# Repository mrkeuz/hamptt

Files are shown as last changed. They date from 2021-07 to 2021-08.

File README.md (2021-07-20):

Ham PTT
=======

Bluetooth PTT switch for ham radio transmitters like Baofeng UV-5R.  
Board helps to control transmitter from PC.

Motivation
----------

Testing of UART interface showed unstable connection. During transmit via UART an usb-ttl 
chip periodically crashes and stops working. Cause is some radio strong interference 
on USB cable. So Bluetooth serial protocol stack (SSP) chosen instead.

Schematic
---------

Host -> (Bluetooth) -> Esp-32 Arduino -> Relay -> Transmitter PTT button

* Hardware

    - Host PC with Bluetooth (tested Ubuntu 20.04)
    - Esp32 DevKit v1 (or similar esp32)
    - Relay shield
    - Baofeng UV-5R

Examples
--------

- Find BT devices `hcitool scan`
- Python

```python3
from hamptt import open_ptt

with open_ptt(bt_addr="A0:B1:C2:D3:E4:F5") as ptt:
    ptt.begin()
    # I.e. play message to transmitter or something else
    ptt.end()
```

Install
-------

* Host PC machine

    - Python 3.8
    - Bluetooth's libs (required for pybluez)

      ```shell
      sudo apt-get install bluez libbluetooth-dev
      ```

    - Pip
      ```shell
      python3 -m pip install "hamptt[bt]"
      ```

* Esp32

    - Upload sketch to your esp-32 via PlatformIO  
      NOTE! Check your board config in `platformio.ini` (see: https://platformio.org/)
      ```
      pio run -t upload
      ``` 

    - Connect pins Esp-32 to relay

        - VVC -> Relay +
        - GND -> Relay -
        - GPIO D25 -> Relay IN

    - Connect relay and audio, for Baofeng UV-5R it looks like:

      Baofeng UV-5R Pins  
      NOTE: You can rebuild your hands-free cable or buy another one

Development
===========

* Build and install
  ```shell
  pip3 uninstall hamptt
  rm -rf dist && poetry build && pip3 install ./dist/*.whl
  ```
  
* Publish
  - Prepare  
     ```shell
    poetry config repositories.testpypi https://test.pypi.org/legacy/
    poetry config pypi-token.testpypi <TOKEN>
    
    poetry config repositories.pypi https://upload.pypi.org/legacy/
    poetry config pypi-token.pypi <TOKEN>
    ```  
  
  - Publish
    ```shell
    poetry publish --build -r testpypi
    
    poetry publish --build -r pypi
    ````

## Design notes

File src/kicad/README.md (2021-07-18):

Esp32 PTT HAT
=============

PTT where using darlington array fot PTT instead relay. Compatible with `ESP32 WROOM DevKit v1` board

Screenshots
-----------  
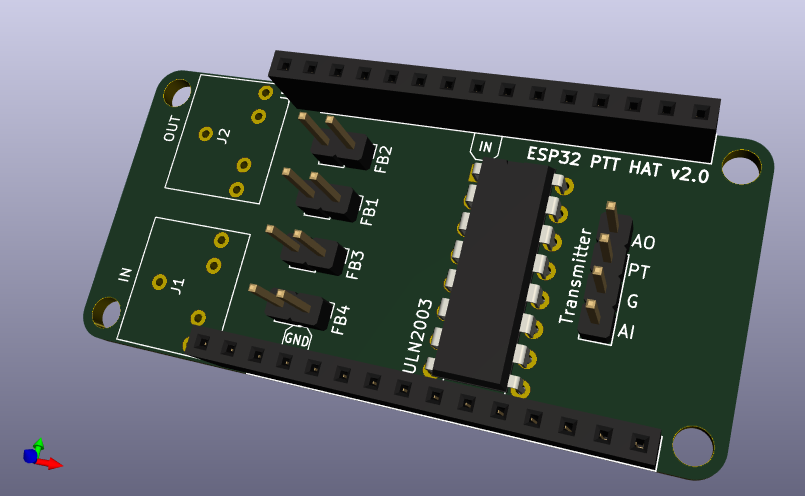
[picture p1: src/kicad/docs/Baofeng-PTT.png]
Esp32 PTT HAT


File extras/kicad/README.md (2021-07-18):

Esp32 PTT HAT
=============

PTT where using darlington array fot PTT instead relay. Compatible with `Esp32-wroom-devkit-v1` board

Looks like this:
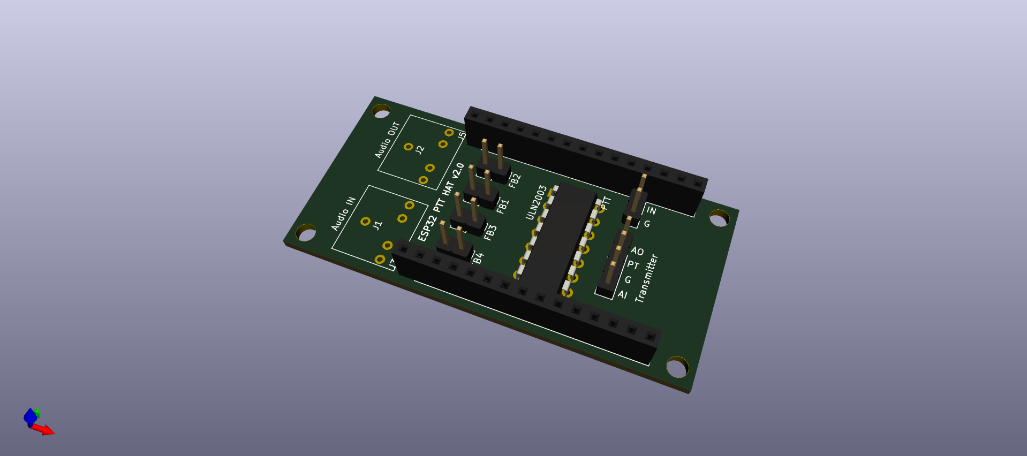
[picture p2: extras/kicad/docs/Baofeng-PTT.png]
Esp32 PTT HAT


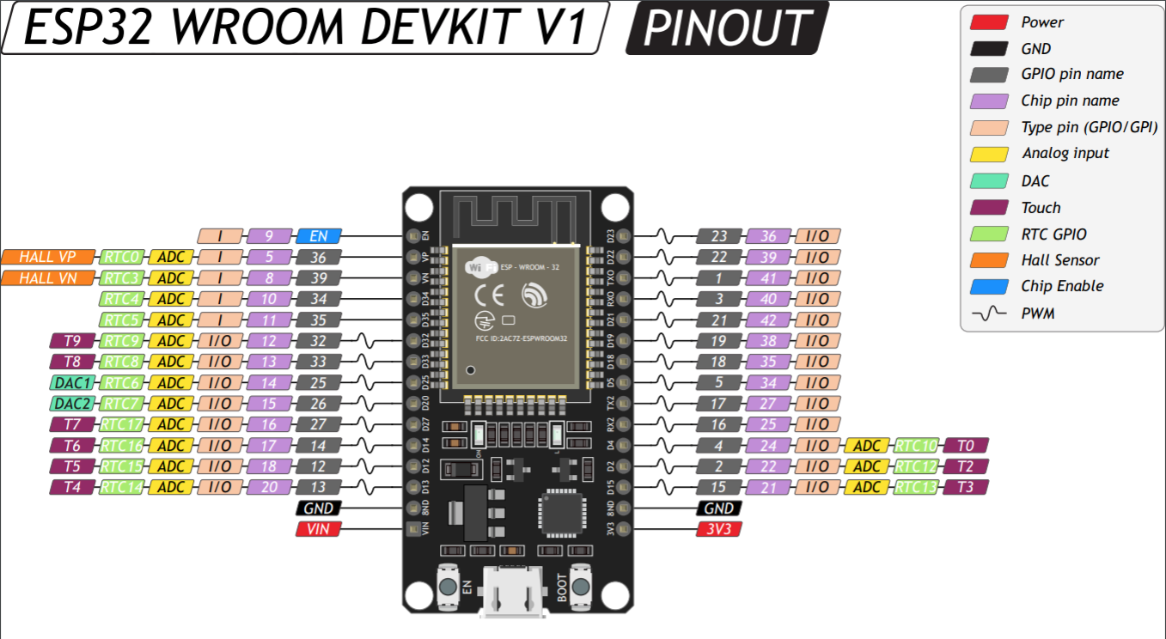
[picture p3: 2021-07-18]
docs/esp32-wroom-wifi-devkit-v1_pinout.png

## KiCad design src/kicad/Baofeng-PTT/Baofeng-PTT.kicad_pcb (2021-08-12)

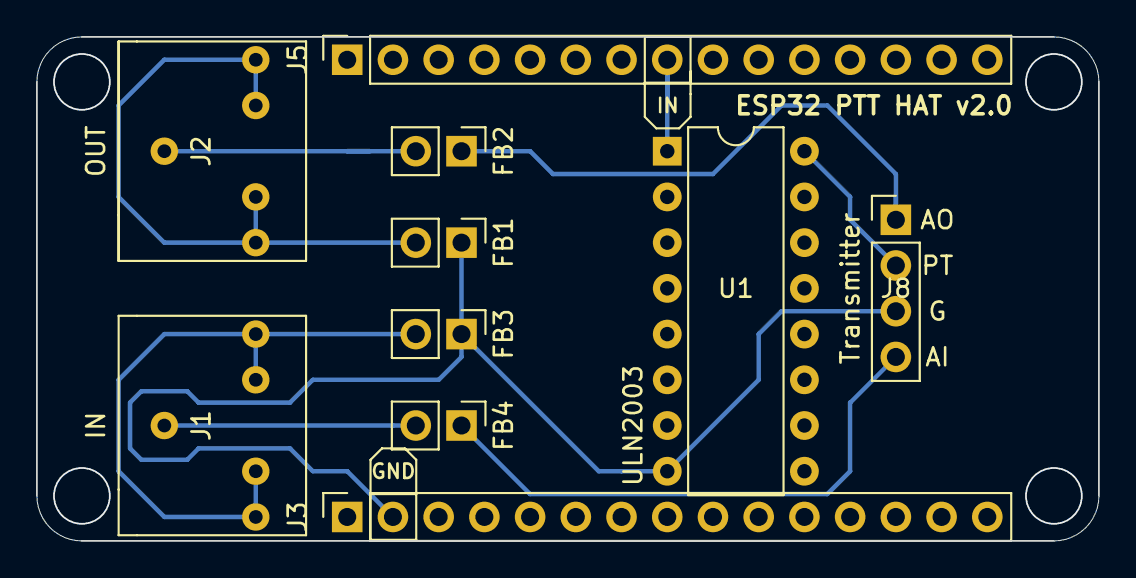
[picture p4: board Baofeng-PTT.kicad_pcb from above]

Board: 2 copper layers, 59.0 x 28.0 mm, 10 parts (0 on the bottom side), 9 nets.

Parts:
FB1, FB2, FB3, FB4: Ferrite_Bead; PinHeader_1x02_P2.54mm_Vertical
J1: IN; Audio_5conn
J2: OUT; Audio_5conn
J3: Conn_01x15; PinSocket_1x15_P2.54mm_Vertical
J5: Esp32; PinSocket_1x15_P2.54mm_Vertical
J8: Transmitter; PinHeader_1x04_P2.54mm_Vertical
U1: ULN2003; DIP-16_W7.62mm

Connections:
AI: FB4.1, J8.4
AO: FB2.1, J8.1
D25: J5.8, U1.1
GND: FB1.1, FB3.1, J3.2, J8.3, U1.8
unnamed: FB1.2, J2.R, J2.S
unnamed: FB2.2, J2.T
unnamed: FB3.2, J1.R, J1.S
unnamed: FB4.2, J1.T
PT: J8.2, U1.16

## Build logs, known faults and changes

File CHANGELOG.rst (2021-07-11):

=========
Changelog
=========

Version 0.0.3
=============

- Add background "ping" BT for stable connection and avoid long connection

Version 0.0.2
===========

- Add Bluetooth PTT support

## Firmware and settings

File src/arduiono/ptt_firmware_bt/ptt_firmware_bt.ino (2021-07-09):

void(* reset) (void) = 0; //Reset function

#include "BluetoothSerial.h" 

BluetoothSerial ESP_BT; 

const int LED_PIN = 2;
const int TX_PIN = 25;

unsigned long currentMillis = 0;
unsigned long previousMillis = 0;
unsigned long lastTxMillis = 0;
unsigned long lastCommandMillis = 0;
boolean tx = false;

const long txTimout = 15000;
const long commandTimout = 60000;


long runSign = random(0, 2147483646L);


// the setup routine runs once when you press reset:
void setup() {
  // initialize serial communication at 9600 bits per second:
  Serial.begin(115200);
  ESP_BT.begin("Baofeng PTT 1");

  pinMode(TX_PIN, OUTPUT);
  pinMode(LED_PIN, OUTPUT);

  digitalWrite(TX_PIN, LOW);
  digitalWrite(LED_PIN, LOW);

  Serial.println("Starting...");
}

// the loop routine runs over and over again forever:
void loop() {
  
  //Check hang bt or other problems
  if(tx && millis() > lastTxMillis + txTimout){
      Serial.println("TX seems hang. Rebooting...");
      stopTx();
      reset();
  }

  //Check BT stack hang
  if(millis() > lastCommandMillis + commandTimout){
      Serial.println("Timeout. No input commands. Seems BT hang. Rebooting...");
      stopTx();
      reset();
  }

  blinkTik();

  if (ESP_BT.available()) {

    lastCommandMillis = millis();

    readBlink();

    // read byte
    char incomingByte = toupper(ESP_BT.read());

    switch (incomingByte) {
      case 'T':
        startTx();
        break;

      case 'C':
        ESP_BT.print("WORK");
        break;

      case 'L':
        //noop
        break;

      case 'S':
        ESP_BT.print("Run sign: ");
        ESP_BT.println(runSign);
        break;

      case 'K':
        ESP_BT.print("Reboot");
        reset();
        break;

      case 'H':
        ESP_BT.println("Commands: ");
        ESP_BT.println("  \"T\" - transmit (PTT ON)");
        ESP_BT.println("  \"R or any char\" - receive (PTT OFF)");
        ESP_BT.println("  \"C\" - check, print 'WORK' string");
        ESP_BT.println("  \"S\" - print unique run sign number (changes when restart or reconnect)");
        ESP_BT.println("  \"K\" - restart arduino");
        ESP_BT.println("  \"L\" - keepalive package");
        break;

      default:
        stopTx();
    }
  }
}

void startTx(){
  ESP_BT.print("TX");
  digitalWrite(TX_PIN, HIGH);
  lastTxMillis = millis();
  tx = true;
}

void stopTx(){
  ESP_BT.print("RX");
  digitalWrite(TX_PIN, LOW);
  tx = false;
}

void readBlink() {
  currentMillis = millis();
  digitalToggle(LED_PIN);
}

void blinkTik() {

  long restBlinkInterval;
  
  if (tx){
    restBlinkInterval = 25;  
  } else {
    restBlinkInterval = 1000;
  }

  currentMillis = millis();

  if (currentMillis - previousMillis >= restBlinkInterval) {
    // save the last time you blinked the LED
    previousMillis = currentMillis;

    digitalToggle(LED_PIN);
  }

}

inline void digitalToggle(byte pin) {
  digitalWrite(pin, !digitalRead(pin));
}

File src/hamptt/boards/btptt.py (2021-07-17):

import logging
from threading import Lock

import bluetooth  # type: ignore
from func_timeout import func_set_timeout  # type: ignore

from hamptt.boards.abstptt import AbstractPtt

_logger = logging.getLogger(__name__)


class BtPtt(AbstractPtt):
    _send_lock: Lock = Lock()

    def __init__(self, bd_addr):
        self.sock = bluetooth.BluetoothSocket(bluetooth.RFCOMM)
        port = 1
        self.sock.connect((bd_addr, port))

    def begin(self):
        recv = self._send_recv("t")
        if recv != b"TX":
            raise ConnectionError(f"Cannot start transmit. Transmitter return '{recv}', but expected 'TX'")

    def end(self):
        recv = self._send_recv("r")
        if recv != b"RX":
            raise ConnectionError(f"Cannot end transmit. Transmitter return '{recv}', but expected 'RX'")

    @func_set_timeout(2.5)
    def _send_recv(self, data):
        try:
            self._send_lock.acquire()

            self.sock.send(data)
            answer = b""
            answer += self.sock.recv(1500)
            return answer
        finally:
            self._send_lock.release()

    @func_set_timeout(2.5)
    def _send(self, data):
        try:
            self._send_lock.acquire()
            self.sock.send(data)
        finally:
            self._send_lock.release()

    def close(self):
        try:
            self.end()
            self._send_lock.acquire()
            _logger.debug("Close socket")
            self.sock.close()
        finally:
            self._send_lock.release()

    def ping(self):
        _logger.debug("Ping BT PTT")
        recv = self._send_recv("C")
        if recv != b"WORK":
            raise ConnectionError(f"Cannot ping device. Got answer '{recv}', but expected 'WORK'")


if __name__ == '__main__':
    ptt = BtPtt("00:00:00:00:00:00")

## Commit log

2020-06-24 Fix code style
    Flake8 fixes
    [btptt.py]
2021-07-09 Add new pcb for exclude relay module and to add audio normalize
    Replace relay module to ULN2003 switch
    Add in/out audio level normalizer
    [Baofeng-PTT.kicad_pcb, Baofeng-PTT.sch]
2021-07-09 Next version of pcb
    Reduce size of pcb
    [Baofeng-PTT.kicad_pcb, Baofeng-PTT.sch]
2021-07-11 Cleanup project
    [Baofeng-PTT.kicad_pcb, Baofeng-PTT.sch]
2021-07-18 Cleanup kikad
    [Baofeng-PTT.kicad_pcb, Baofeng-PTT.sch]
2021-07-18 Cleanup Kikad project
    [Baofeng-PTT.kicad_pcb, Baofeng-PTT.sch]
2021-07-18 Minor refactoring arduino
2021-07-18 Move kikad project to src folder
    [Baofeng-PTT.kicad_pcb, Baofeng-PTT.sch]
2021-07-18 Minor PCB changing
    [Baofeng-PTT.kicad_pcb]
2021-08-12 Minor change pcb
    [Baofeng-PTT.kicad_pcb]
